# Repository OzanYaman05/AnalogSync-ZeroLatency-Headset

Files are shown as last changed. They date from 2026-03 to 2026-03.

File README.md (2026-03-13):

# 🎧 AnalogSync: Open-Source Zero-Latency Wireless Headset





Welcome to the **AnalogSync** project! This is a 100% open-source, DIY wireless headset system built from scratch. Unlike standard Bluetooth headphones that suffer from digital compression and audio latency, this project uses **pure analog FM transmission** to achieve **true zero-latency** and **Hi-Fi Stereo** sound. 

Whether you are a gamer, musician, or hardware enthusiast, you can buy the parts, 3D print the shell, and build your own latency-free wireless audio system!

## ✨ Key Features
* **Zero Latency (0ms):** End-to-end analog signal processing. Perfect for gaming and lip-syncing.
* **Bare-Metal I2C Control:** Custom firmware bypassing standard libraries to directly control IC registers (RDA5807M & KT0803L) for advanced stereo and bass management.
* **Optimized Power Management:** Engineered impedance matching for the TDA1308 Class-AB amplifier driving 8-Ohm speakers.
* **100% 3D Printable:** Custom-designed ergonomic headset shell and headband.

---

## 🛠️ Bill of Materials (BOM) - What You Need
Anyone can build this! Here is the complete list of parts:

**Receiver (The Headset):**
* 1x ATtiny85 Microcontroller (Overclocked to 8MHz internal)
* 1x RDA5807M FM Stereo Receiver Module
* 1x TDA1308 Class-AB Headphone Amplifier
* 2x 32mm 8-Ohm Speakers
* 2x 3.7V Li-Po Batteries & Charging Module (e.g., TP4056) **OR** 4x AA Batteries
* Assorted Capacitors & Resistors (See Schematics)

**Transmitter (The Base Station):**
* 1x Arduino (Nano or Uno)
* 1x KT0803L FM Transmitter Module *(Note: Almost any standard FM transmitter module can work!)*
* 2x Push Buttons (For frequency tuning)
* Audio Jack / Aux Cable

---

## 🚀 How to Build It (DIY Guide)

### Step 1: 3D Print or Remix the Enclosure
Navigate to the `/Mechanical` folder. As a true open-source hardware project, we currently provide the raw **Fusion 360 (`.f3d`) source files**. You can modify the parametric design to fit your head perfectly, and export the `.STL` files directly from your software to print using PLA or PETG (20% infill is recommended). *(Pre-sliced .STL files will be added in the future!)*

### Step 2: The Hardware & Solder
Check the `/Hardware` folder for the wiring diagram. 
* **Note on Amplifier:** Ensure you add a 680uF decoupling capacitor at the output of the TDA1308 to protect the 8-Ohm speakers and prevent voltage drops!

### Step 3: Flash the Firmware
Navigate to the `/Firmware` folder.
* **RX (Headset):** Flash the ATtiny85. *Make sure to burn the bootloader to 8MHz internal clock first!*
* **TX (Base):** Upload the Arduino sketch. The buttons on Pin 2 and Pin 3 allow you to scan frequencies (Default lock: 82.0 MHz).

### Step 4: Assemble & Enjoy
Put the electronics inside your fresh 3D prints, power up the transmitter with an audio source, and enjoy your zero-latency analog sound!

---

## 🤝 Contributing
Feel free to fork this project, submit pull requests, or open an issue if you have ideas to improve the audio quality or 3D design. Let's make open-source hardware better together!

## 📝 License
This project is licensed under the MIT License - see the [LICENSE](LICENSE) file for details.

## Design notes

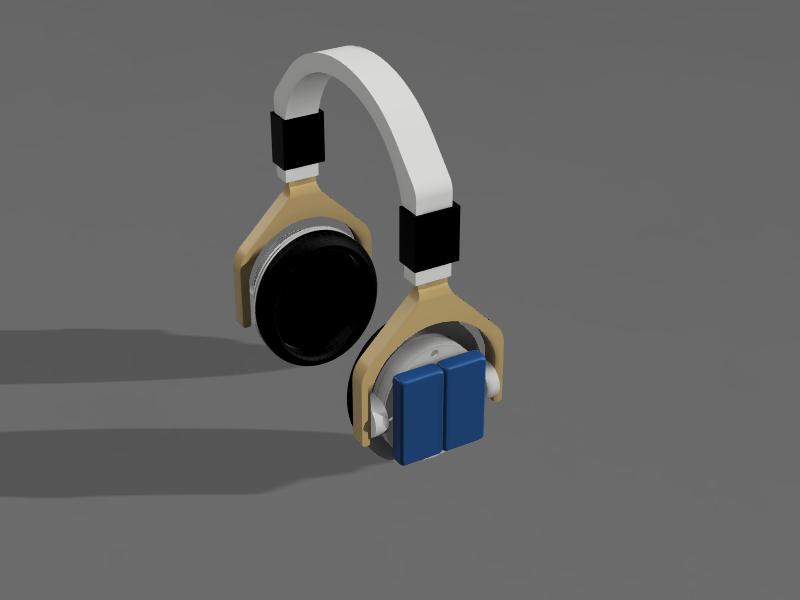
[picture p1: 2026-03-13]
Images/AnalogSynacRender2.png

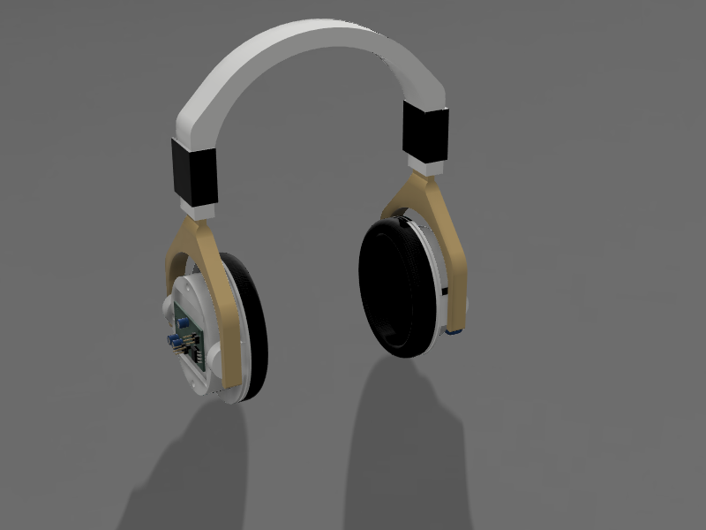
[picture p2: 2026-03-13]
Images/AnalogSyncRender1.png

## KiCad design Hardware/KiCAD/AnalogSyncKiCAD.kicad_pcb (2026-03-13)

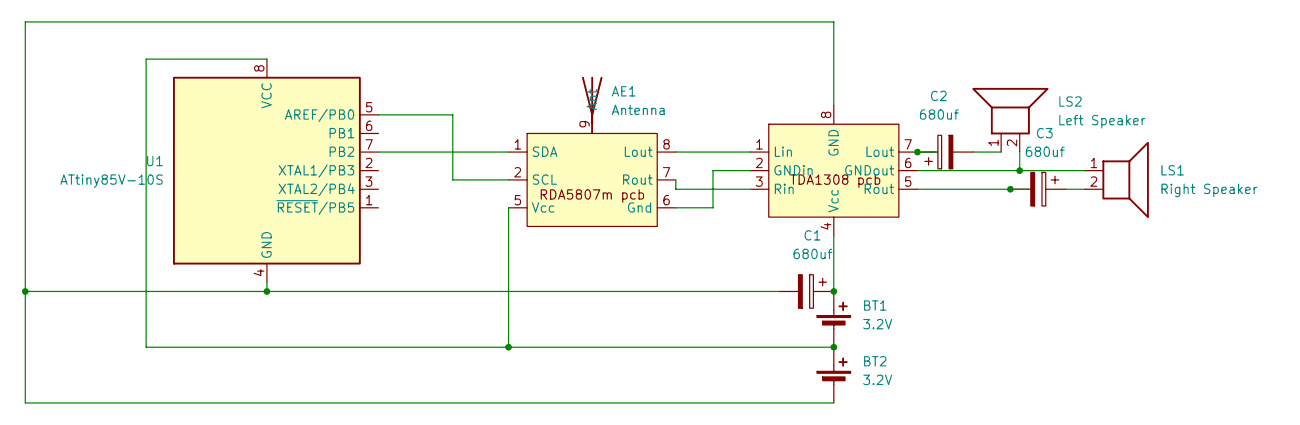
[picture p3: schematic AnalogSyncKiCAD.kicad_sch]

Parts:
AE1: Antenna; PinHeader_1x01_P2.54mm_Vertical
BT1, BT2: 3.2V; PinHeader_1x02_P2.54mm_Vertical
C1, C2, C3: 680uf; CP_Radial_D6.3mm_P2.50mm
LS1: Right Speaker; PinHeader_1x02_P2.54mm_Vertical
LS2: Left Speaker; PinHeader_1x02_P2.54mm_Vertical
RDA5807m1: RDA5807m pcb
TDA1308pcb2: tda1305 pcb
U1: ATtiny85V-10S; DIP-8_W10.16mm

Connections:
unnamed: AE1.1 (A), RDA5807m1.9 (Ant)
unnamed: BT1.1 (+), C1.1, TDA1308pcb2.4 (Vcc)
unnamed: BT1.2 (-), BT2.1 (+), RDA5807m1.5 (Vcc), U1.8 (VCC)
unnamed: BT2.2 (-), C1.2, TDA1308pcb2.8 (GND), U1.4 (GND)
unnamed: C2.2, LS2.1
unnamed: C3.1, LS1.2
unnamed: RDA5807m1.7 (Rout), TDA1308pcb2.3 (Rin)
unnamed: RDA5807m1.6 (Gnd), TDA1308pcb2.2 (GNDin)
unnamed: RDA5807m1.2 (SCL), U1.5 (AREF/PB0)
unnamed: RDA5807m1.1 (SDA), U1.7 (PB2)
unnamed: RDA5807m1.8 (Lout), TDA1308pcb2.1 (Lin)
unnamed: LS1.1, LS2.2, TDA1308pcb2.6 (GNDout)
unnamed: C2.1, TDA1308pcb2.7 (Lout)
unnamed: C3.2, TDA1308pcb2.5 (Rout)

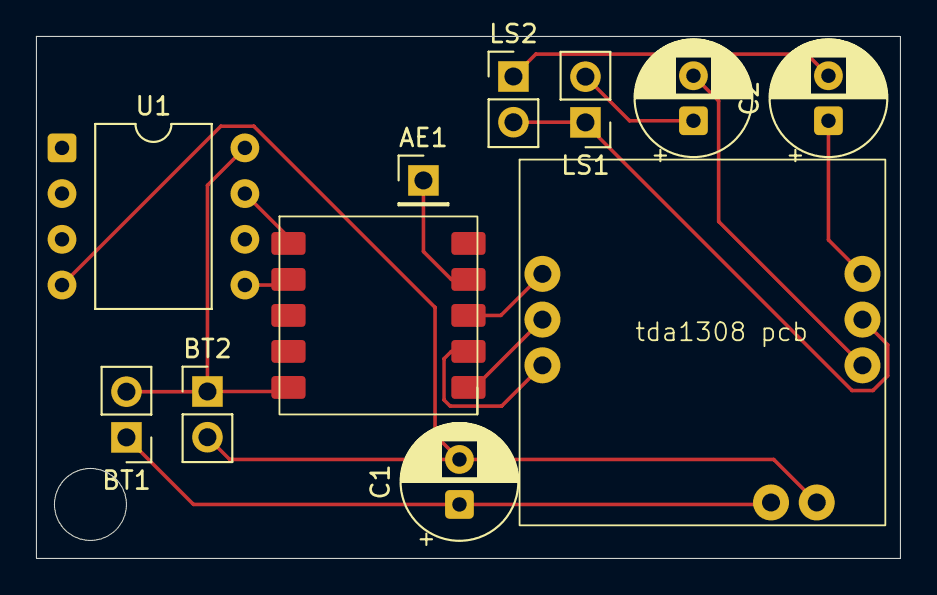
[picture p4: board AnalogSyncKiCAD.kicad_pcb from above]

Board: 2 copper layers, 48.0 x 29.0 mm, 11 parts (0 on the bottom side), 14 nets.

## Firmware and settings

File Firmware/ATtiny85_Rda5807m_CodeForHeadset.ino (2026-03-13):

#include <TinyWireM.h>

#define RDA_ADDR 0x10 // Sequential Mode

void setup() {
  TinyWireM.begin();
  delay(500); 

  TinyWireM.beginTransmission(RDA_ADDR);

  // 1. Register 02H: start, Stereo, Bass Boost off
  TinyWireM.write(0xC0); 
  TinyWireM.write(0x01);

  // 2. Register 03H: 82.0 MHz
  // 82.0 MHz : 60 (Hex: 0x3C)
  // BAND: 10 (76-108 MHz) -> Bit 2 , 3
  TinyWireM.write(0x0F); 
  TinyWireM.write(0x18); 

  // 3. Register 04H: default
  TinyWireM.write(0x00);
  TinyWireM.write(0x00);

  // 4. Register 05H: volume 10/15  higher values than 10 can mess up the sound quality
  TinyWireM.write(0x84);
  TinyWireM.write(0xDA); 

  TinyWireM.endTransmission();
}

void loop() {}

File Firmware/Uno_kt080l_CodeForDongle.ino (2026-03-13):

#include <Wire.h>
#include <KT0803.h>

KT0803L radio;

float frequency = 82.0; // Default startup frequency (82.0 MHz)
int bassLevel = 0;      // 0:Off, 1:5%, 2:10%, 3:15%

void setup() {
  Serial.begin(9600);
  Wire.begin();
  
  radio.begin(frequency, false);
  
  Serial.println("\n--- ADVANCED AUDIO AND FREQUENCY CONTROL ---");
  Serial.println("Serial : Type 'f[number]' to set frequency via Serial Monitor (e.g., f82.5)");
  Serial.println("Serial : Type 'b[0-3]' to set Bass Boost level");
  Serial.println("----------------------------------------\n");
  
  updateFrequency(frequency); // Send initial frequency to the radio
}

void loop() {
  // --- SERIAL CONTROL (Allows entering frequency/bass via Serial Monitor) ---
  if (Serial.available() > 0) {
    String data = Serial.readStringUntil('\n');
    data.trim();
    
    if (data.length() > 1) {
      char command = toLowerCase(data.charAt(0));
      String value = data.substring(1);
      
      // 'f' command to set frequency directly from Serial Monitor
      if (command == 'f') {
        frequency = value.toFloat();
        updateFrequency(frequency);
      } 
      // 'b' command to set bass boost level
      else if (command == 'b') {
        bassLevel = value.toInt();
        if (bassLevel >= 0 && bassLevel <= 3) {
          setBassBoost(bassLevel);
          Serial.print(">> BASS BOOST: "); Serial.print(bassLevel * 5); Serial.println("%");
        }
      }
    }
  }
}

// Helper function to set frequency and print it to the Serial Monitor
void updateFrequency(float newFrequency) {
  radio.setFrequency(newFrequency);
  Serial.print(">> NEW FREQUENCY: "); 
  Serial.println(newFrequency, 1); // Display 1 decimal place (e.g., 82.1)
}

// Configures Bass Boost by directly accessing KT0803L Registers via I2C (Bare-metal style)
void setBassBoost(int level) {
  Wire.beginTransmission(0x3E); // KT0803L I2C address
  Wire.write(0x04);             // Target register address
  
  byte regVal = 0x00;           // Clear default
  regVal |= (level & 0x03); 
  
  Wire.write(regVal);
  Wire.

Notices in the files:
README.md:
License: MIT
